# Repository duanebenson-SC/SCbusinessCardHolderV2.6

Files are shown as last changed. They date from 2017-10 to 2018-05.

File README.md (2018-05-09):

# SCbusinessCardHolderV2.6
Screaming Circuits business card holder, V2.6.

The second publicly released version of our electronic business card holder. V2.6 has most ports brought out to headers, and a different battery. Note that the silk screen calles out a CR2032 cell, but it actually takes a pair of CR1220 coin cells.

The Screaming Circuits business card holder is a multi-function device intended for your amusement and as a demonstration of our workmanship.

The current version of the card holder, V2.6, uses a PIC18F46K22 microcontroller. The design will work fine with other members of the PIC18F??K22 family. However, it you change the variant, you will need to uncomment the corresponding #define in globals.h, under the personality settings section.

The .brd and .sch are CAD files for Autodesk Eagle version 8.5 or newer.

Operation:
1. Turn on power and place cards between the header pins and user buttons. The dievice will sleep until a card is removed.

2. The bottom edge of the board has a small ruler, marked in inches and fractions of an inch.

3. With power on, hold the device so the ruler on on a flat surface. As you tilt it side to side, the LEDs will act as a bubble level

4. With power off, if you hold both buttons and then turn power on, all the LEDs will light up. Pressing User 2 will switch to normal mode.
4a. Press and hold User 1 and power on will light up all green LEDs.
4b. Press and hold User 2 and power on will light up all red LEDs.

5. With power on, pressing the User buttons will run a quick flashing patterm - unique for each button.

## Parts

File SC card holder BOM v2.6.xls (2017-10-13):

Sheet: BOM
Item # | Qty | Ref Des | Manufacturer | Manf part num | DigiKey Part number | Description | Package | Type | Side | Notes | Qty 1 | $ Ext | Qty 550 | Qty needed @550 | Ord Qty | $ Ext
1 | 1 | U1 | Microchip | PIC18F46K22-I/MV | PIC18F46K22-I/MV-ND | MCU | UQFN40 | BGA | Top |  | 2.29 | 2.29 | 1.9 | 550 | 600 | 1140.00
2 | 1 | U2 | Freescale | MMA8452QR1 | MMA8452QR1CT-ND | Accelerometer | QFN16 | BGA | Top |  | 1.43 | 1.43 | 1.02 | 550 | 600 | 612.00
3 | 10 | D1, D3, D5, D7, D9, D11, D13, D15, D17, D19 | Kingbright | APHHS1005SURCK | 754-1104-1-ND | LED red | 0402 | SMT | Top |  | 0.44 | 4.40 | 0.14928 | 5500 | 6000 | 895.68
4 | 9 | D2, D4, D6, D8, D10, D12, D14, D16, D18 | Kingbright | APG1005CGC-T | 754-1811-1-ND | LED green | 0402 | SMT | Top |  | 0.46 | 4.14 | 0.0936 | 4950 | 5500 | 514.80
5 | 5 | C1, C2, C3, C4, C5 | Taiyo | LMK105BJ104KV-F | 587-1227-1-ND | .1uf | 0402 | SMT | Top |  | 0.10 | 0.50 | 0.00325 | 2750 | 3000 | 9.75
6 | 1 | C6 | Samsung | CL05A475MQ5NRNC | 1276-1056-1-ND | 4.7uf | 0402 | SMT | Top |  | 0.21 | 0.21 | 0.0485 | 550 | 600 | 29.10
7 | 19 | R1-R19 | Stackpole | RMCF0402JT180R | RMCF0402JT180RCT-ND | 180 ohms | 0402 | SMT | Top |  | 0.10 | 1.90 | 0.00173 | 10450 | 12000 | 20.76
8 | 3 | R20, R21, R22 | Stackpole | RMCF0402JT10K0 | RMCF0402JT10K0CT-ND | 10K | 0402 | SMT | Top |  | 0.10 | 0.30 | 0.00328 | 1650 | 2000 | 6.56
9 | 1 | S1 | C&K Components | JS202011SCQN | 401-2002-1-ND | DPDT switch |  | SMT | Top |  | 0.46 | 0.46 | 0.3031 | 550 | 500 | 151.55
10 | 2 | S2, S3 | C&K Components | PTS645SK50SMTR92 LFS | CKN9087CT-ND | Momentary push |  | SMT | Top |  | 0.25 | 0.50 | 0.13125 | 1100 | 1200 | 157.50
11 | 2 | B1, B2 | MPD | BK-883 | BK-883-ND | 2032 holder |  | SMT | Bottom |  | 0.35 | 0.70 | 0.2448 | 1100 | 1200 | 293.76
12 | 2 | H1, H2 | Sullins | PREC006SFAN-RC | S1212EC-06-ND | 1x6 header ICSP |  | DNS | Top |  | 0.20 | 0.40 | 0.11586 | 1100 | 1200 | 139.03
13 | 4 | F1, F2, F3, F4 | 3M | SJ61A1 | SJ5746-0-ND | Rubber foot |  | DNS | Bottom |  | 0.10 | 0.39 | 0.0787 | 2200 | 2400 | 188.88
14 | 2 | Batt1, Batt2 | Energizer | CR2032VP | N189-ND | CR2032 battery |  | DNS | Bottom |  | 0.33 | 0.66 | 0.18411 | 1100 | 1200 | 220.93
 |  |  |  |  |  | PCB 3.5" x 1.65" |  |  |  |  |  | 0.00
 |  |  |  |  |  |  |  |  |  |  | Total parts, Qty 1 | 18.28 |  | Total parts, Qty 550 | 7.96 | 4380.30
 | Items 12, 13, and 14 need to be ordered and delivered to me, but not placed on the board |  |  |  |  |  |  | Assembly quote summary
 |  |  |  |  |  |  | BOM line items | 11
 | Note that item #13, the 3M feet only come in sheets of 144 |  |  |  |  |  | BGA | 2
 |  |  |  |  |  |  | SMT | 52
 |  |  |  |  |  |  | Thru-hole | 0
 |  |  |  |  |  |  | Total | 54

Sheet: LED
System V | 3
Diode drop | 0.385
 | 2.615
LED V | 1.95
C | 0.0036 | Max LED C | 0.0828
R V | 0.665
R Ohm | 184.7222222

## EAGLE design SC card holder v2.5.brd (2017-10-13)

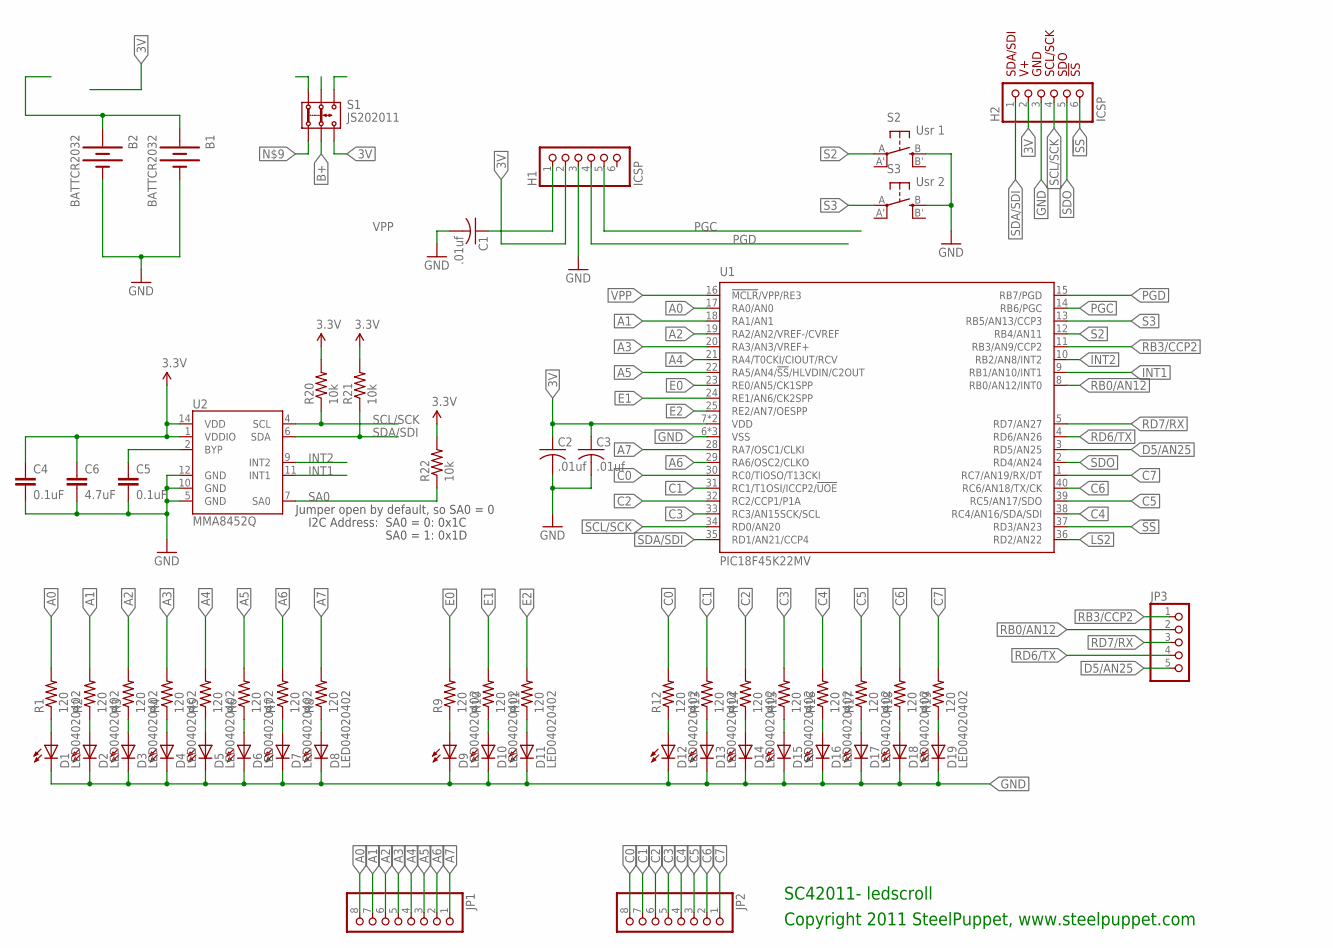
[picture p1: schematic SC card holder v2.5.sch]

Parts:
B1, B2: BATTCR2032; BATT_2032_SMT
C1, C2, C3: .01uf; C0402K
C4, C5: 0.1uF; 0402-CAP
C6: 4.7uF; 0402-CAP
D1, D2, D3, D4, D5, D6, D7, D8, D9, D10, D11, D12, D13, D14, D15, D16, D17, D18, D19: LED04020402; LED0402
H1, H2: ICSP; 1X06-S
JP1, JP2: PINHD-1X08_2.54-S; 1X08-S
JP3: PINHD-1X05_2.54-S; 1X05-S
R1, R2, R3, R4, R5, R6, R7, R8, R9, R10, R11, R12, R13, R14, R15, R16, R17, R18, R19: 120; R0402
R20, R21, R22: 10k; 0402-RES
S1: JS202011; JS202011SMT
S2: Usr 1; EVQ-Q2
S3: Usr 2; EVQ-Q2
U1: PIC18F45K22MV; QFN40-5X5
U2: MMA8452Q; QFN-16_0.5MM

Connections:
3V: C2.1, C3.1, C4.1, C6.1, H1.2, H2.2, R20.2, R21.2, R22.2, S1.3 (3.2), S1.4 (3.1), U1.7 (VDD), U1.26 (VDD), U2.1 (VDDIO), U2.14 (VDD)
!SS: H2.6, U1.37 (RD3/AN23)
A0: JP1.8, R1.2, U1.17 (RA0/AN0)
A1: JP1.7, R2.2, U1.18 (RA1/AN1)
A2: JP1.6, R3.2, U1.19 (RA2/AN2/VREF-/CVREF)
A3: JP1.5, R4.2, U1.20 (RA3/AN3/VREF+)
A4: JP1.4, R5.2, U1.21 (RA4/T0CKI/CIOUT/RCV)
A5: JP1.3, R6.2, U1.22 (RA5/AN4/!SS!/HLVDIN/C2OUT)
A6: JP1.2, R7.2, U1.29 (RA6/OSC2/CLKO)
A7: JP1.1, R8.2, U1.28 (RA7/OSC1/CLKI)
B+: B1.1 (+), B1.3 (+), B2.1 (+), B2.3 (+), S1.2 (2.2), S1.5 (2.1)
BYP: C5.1, U2.2 (BYP)
C0: JP2.8, R12.2, U1.30 (RC0/TIOSO/T13CKI)
C1: JP2.7, R13.2, U1.31 (RC1/T1OSI/ICCP2/!UOE)
C2: JP2.6, R14.2, U1.32 (RC2/CCP1/P1A)
C3: JP2.5, R15.2, U1.33 (RC3/AN15SCK/SCL)
C4: JP2.4, R16.2, U1.38 (RC4/AN16/SDA/SDI)
C5: JP2.3, R17.2, U1.39 (RC5/AN17/SDO)
C6: JP2.2, R18.2, U1.40 (RC6/AN18/TX/CK)
C7: JP2.1, R19.2, U1.1 (RC7/AN19/RX/DT)
D5/AN25: JP3.5, U1.3 (RD5/AN25)
E0: R9.2, U1.23 (RE0/AN5/CK1SPP)
E1: R10.2, U1.24 (RE1/AN6/CK2SPP)
E2: R11.2, U1.25 (RE2/AN7/OESPP)
GND: B1.2 (-), B2.2 (-), C1.2, C2.2, C3.2, C4.2, C5.2, C6.2, D1.C, D2.C, D3.C, D4.C, D5.C, D6.C, D7.C, D8.C, D9.C, D10.C, D11.C, D12.C, D13.C, D14.C, D15.C, D16.C, D17.C, D18.C, D19.C, H1.3, H2.3, S2.B (S), S3.B (S), U1.6 (VSS), U1.27 (VSS), U1.41 (VSS), U2.5 (GND), U2.10 (GND), U2.12 (GND)
INT1: U1.9 (RB1/AN10/INT1), U2.11 (INT1)
INT2: U1.10 (RB2/AN8/INT2), U2.9 (INT2)
LS2: U1.36 (RD2/AN22)
unnamed: D1.A, R1.1
unnamed: D2.A, R2.1
unnamed: D3.A, R3.1
unnamed: D4.A, R4.1
unnamed: D9.A, R9.1
unnamed: D10.A, R10.1
unnamed: D11.A, R11.1
unnamed: D13.A, R13.1
unnamed: D14.A, R14.1
unnamed: D15.A, R15.1
unnamed: D12.A, R12.1
unnamed: D6.A, R6.1
unnamed: D7.A, R7.1
unnamed: D16.A, R16.1
unnamed: D17.A, R17.1
unnamed: D8.A, R8.1
unnamed: D5.A, R5.1
unnamed: D18.A, R18.1
unnamed: D19.A, R19.1
PGC: H1.5, U1.14 (RB6/PGC)
PGD: H1.4, U1.15 (RB7/PGD)
RB0/AN12: JP3.2, U1.8 (RB0/AN12/INT0)
RB3/CCP2: JP3.1, U1.11 (RB3/AN9/CCP2)
RD6/TX: JP3.4, U1.4 (RD6/AN26)
RD7/RX: JP3.3, U1.5 (RD7/AN27)
S2: S2.A, U1.12 (RB4/AN11)
S3: S3.A, U1.13 (RB5/AN13/CCP3)
SA0: R22.1, U2.7 (SA0)
SCL/SCK: H2.4, R20.1, U1.34 (RD0/AN20), U2.4 (SCL)
SDA/SDI: H2.1, R21.1, U1.35 (RD1/AN21/CCP4), U2.6 (SDA)
SDO: H2.5, U1.2 (RD4/AN24)
VPP: C1.1, H1.1, U1.16 (!MCLR!/VPP/RE3)

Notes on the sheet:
SC42011- ledscroll
Copyright 2011 SteelPuppet, www.steelpuppet.com
SDA/SDI
GND
SCL/SCK
SDO
!SS
I2C Address:
SA0 = 0: 0x1C
SA0 = 1: 0x1D
Jumper open by default, so SA0 = 0

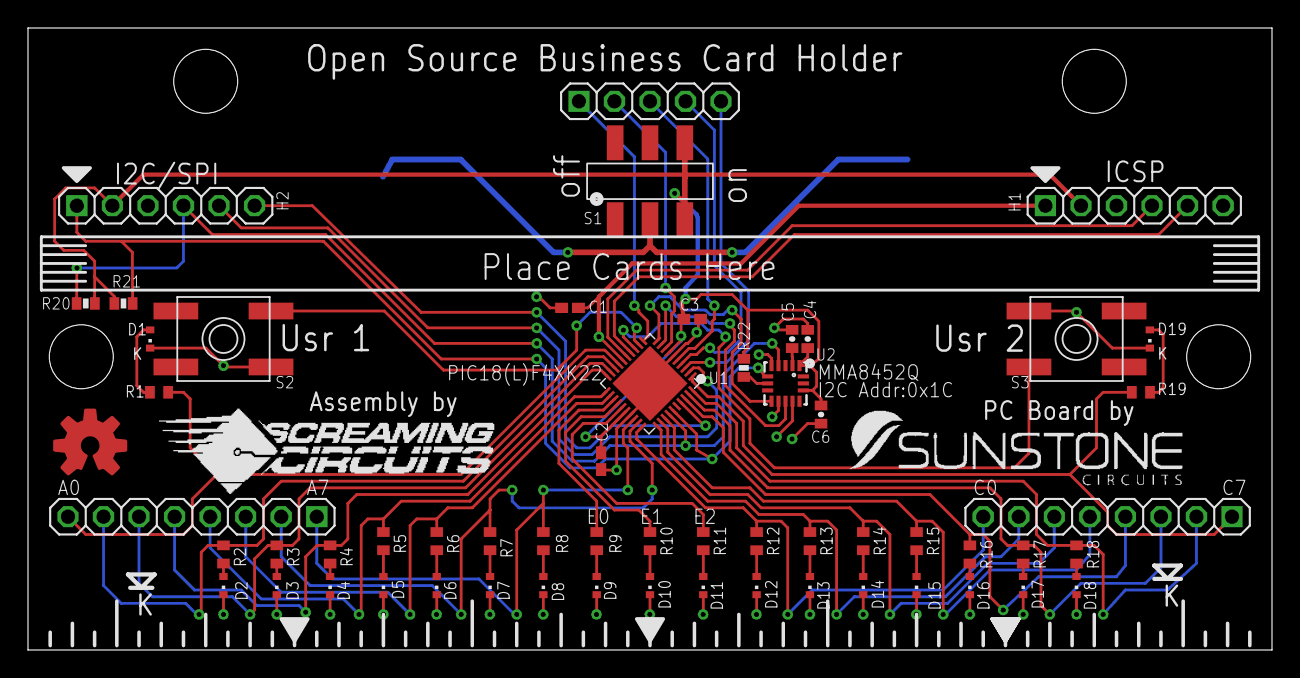
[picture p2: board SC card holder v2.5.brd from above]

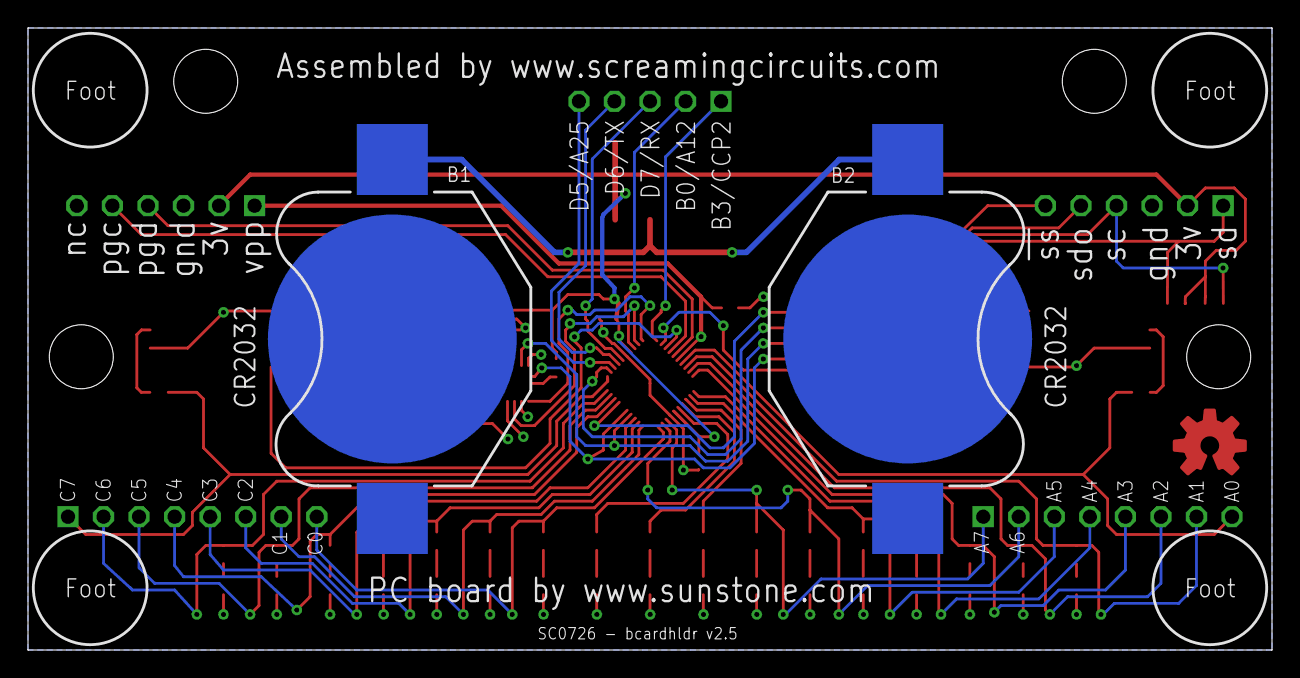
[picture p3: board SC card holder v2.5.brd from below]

Board: 2 copper layers, 88.9 x 44.5 mm, 62 parts (2 on the bottom side), 59 nets.

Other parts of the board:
U$1: SUNSTONE-LOGO
U$2: OSHWLOGO_TOP_0.2
U$3: SC-LOGO

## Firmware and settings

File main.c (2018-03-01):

// ##########################################################################
// ##########################################################################
// Screaming Circuits Business card holder
//
// Written by Duane Benson
// 9/01/16
//
// Open source business card holder and bubble level
//
// Communicates via by I2C
// For MCU: PIC18F46K22 / PIC18F45K22 / PIC18F44K22 / PIC18F43K22
// 
//
// Edit history:
//
// ********************************************

// ####
// #### Project specific notes
// ####

// ####
/*
 * File:   main.c
 * Author: Duane
 *
 * Created on February 21, 2013, 12:06 PM
 */
// #### #### #### #### #### #### #### #### #### #### #### #### #### ####
// #### Defines
// #### #### #### #### #### #### #### #### #### #### #### #### #### ####

/******************************************************************************/
/* Files to Include                                                           */
/******************************************************************************/

#include <xc.h>        /* XC8 General Include File */
#include "globals.h"
#include "system.h"        /* System funct/params, like osc/peripheral config */
#include "user.h"          /* User funct/params, such as InitApp */
#include "configuration_bits.c"

/******************************************************************************/
/* User Global Variable Declaration                                           */
/******************************************************************************/

// See globals.

/******************************************************************************/
/* Main Program                                                               */
/******************************************************************************/

void main(void)
{
    int x, i, y, z;
    char PULSEdata, TRANSdata;

    /* Configure the oscillator for the device */
    ConfigureOscillator();

    /* Initialize I/O and Peripherals for application */
    InitApp();

    // Test patterns
    if (!PORTBbits.RB4 && !PORTBbits.RB5) { // Bothe Usr1 and Usr2 held at start up: All LEDs on
        LED0 = 1;
        LED1 = 1;
        LED2 = 1;
        LATA = 0xff;
        LATC = 0xff;
        delayLong(10);
        while (PORTBbits.RB5);
    } else if (!PORTBbits.RB4) {    // Usr1 held at start: all green LEDs on
        LED1 = 1;
        LATA = 0xAA;
        LATC = 0x55;
        delayLong(10);
        while (PORTBbits.RB5);
    } else if (!PORTBbits.RB5) {    // Usr2 held at start: all red LEDs on
        LED0 = 1;
        LED2 = 1;
        LATA = 0x55;
        LATC = 0xAA;
        delayLong(10);
        while (PORTBbits.RB5);
    }

    LATA = 0x00;
    LATC = 0x00;

    LED1 = 1;
    for (x = 0; x < 10; x++){
        LED0 = !LED0;
        LED1 = !LED1;
        LED2 = !LED2;
        delayLong(1);
    }

    LED0 = 0;
    LED1 = 0;
    LED2 = 0;

    MMAdata = readRegister(0x0D);  // Read WHO_AM_I register
    if (MMAdata == 0x2A) { // WHO_AM_I should always be 0x2A
        initMMA8452(2, 0);  // init the accelerometer if communication is OK
    } else {
        LATA = MMAdata;
        while(1) ; // Loop forever if communication doesn't happen
    }
    
    RBIF = 0;           // Clear flags
    INT1IF = 0;
    INT2IF = 0;
    Usr1 = 0;
    Usr2 = 0;
    Int1 = 0;
    Int2 = 0;

    INTCONbits.GIE = 1;

 // Original while loop to go with the original ISR
    while (1) {
        //if (Usr1 || Xval > 0x90) {
        //    bubbleLevel();
        if (Xval > 0x90) {
            bubbleLevel();
        } else if (Usr1) {
            flashAllOutward(3);
            Usr1 = 0;
        } else if (Usr2) {
            bubbleGum(6);
            Usr2 = 0;
        } else if (Int1) {
            flashAllOutward(1);
            Int1 = 0;
        } else if (Int2) {
            respondToAccel();
            Int2 = 0;
        } else {
            Sleep();
        }
    }
}

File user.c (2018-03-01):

/******************************************************************************/
/* Files to Include                                                           */
/******************************************************************************/

#include <xc.h>        /* XC8 General Include File */
#include "globals.h"
#include "user.h"
#include "system.h"

/******************************************************************************/
/* User Functions                                                             */
/******************************************************************************/

/* <Initialize variables in user.h and insert code for user algorithms.> */

void InitApp(void)
{
    /* TODO Initialize User Ports/Peripherals/Project here */
    TRISA = 0x00;
    TRISB = 0x00;
    TRISC = 0x00;
    TRISD = 0x00;
    TRISE = 0x00;

    LATA  = 0x00;
    LATB  = 0x00;
    LATC  = 0x00;
    LATD  = 0x00;
    LATE  = 0x00;

    ANSELA = 0x00;
    ANSELB = 0x00;
    ANSELC = 0x00;
    ANSELD = 0x00;
    ANSELE = 0x00;

    // Ports set to input for input switches and interrupts
    TRISB   |= 1 << 5;      // RB5 is input: Usr 2
    TRISB   |= 1 << 4;      // RB4 is input: Usr 1
    TRISB   |= 1 << 1;      // RB1 is input: Int 1 from accelerometer
    TRISB   |= 1 << 2;      // RB2 is input: Int 2 from accelerometer

    // Usr1 and Usr2 are normally-open active low. They need to pull-up
    WPUB4 = 1;              // Weak pull-up for RB4 / S2 / Usr 1
    WPUB5 = 1;              // Weak pull-up for RB5 / S3 / Usr 2

    // MMA8452 is set up with open drain, active-low interrupt lines
    //WPUB0 = 0;              // Weak pull-up for Int1
    WPUB1 = 0;              // Weak pull-up for Int1
    WPUB2 = 0;              // Weak pull-up for Int2
    RBPU = 0;               // 0 = enable pull-ups on PORTB, provided individual WPUB bits are set

    // Interrupts
    IPEN  = 0;              // Disable Interrupt prioritoes, as they are not needed
    INTCON = 0b00000000;    // Start with everything cleared

    // MMA8452 is set up with push-pull, active-high interrupt lines
    INTEDG1 = 1;            // Int1 pin interrupt on: 1 = rising edge, 0 = falling edge
    INTEDG2 = 1;            // Int2 pin interrupt on: 1 = rising edge, 0 = falling edge

    IOCBbits.IOCB4 = 1;     // Enable IOC (Interrrupt on change) on pin RB4
    IOCBbits.IOCB5 = 1;     // Enable IOC on pin RB5

    RBIF = 0;               // Clear interrupt flags
    INT1IF = 0;
    INT2IF = 0;

    INT1IE = 1;             // Enable interrupt pin 1: Accelerometer interrupt
    INT2IE = 1;             // Enable interrupt pin 2: Accelerometer interrupt

    RBIE = 1;               // Enable Port B int on change: RB4 and RB5 are Usr 1 and Usr 2

    // Set I2C pins as inputs
    TRISD |= 1 << 0;        // RD0 = SCL2/SCK2
    TRISD |= 1 << 1;        // RD1 = SDA2/SDI2

    SSP2ADD = 0x9F;         // 100 KHz I2C clock with 64 MHz system clock
    SSP2STATbits.SMP = 1;   // Slew off
    SSP2CON1bits.SSPEN = 1; // Enable I2C
    SSP2CON1 = 0b00101000;

// setting and clearing the appropriate SSPxM bits in the SSPxCON1 register and by setting the SSPxEN bit.
}


// Delay time in multiples of 10 ms
void delayLong(unsigned long x) {
    unsigned long i;
    for (i = 0; i < x; i++) {
        __delay_ms(10);
    }
}


void bubbleLevel() {
        GIE = 0;        // Turn off all interrupts
        while(!PORTBbits.RB4 || Xval > 0x90) {
            getAccel();
            LED1 = 1;
            if (Ysign) {
                //Yval = Yval - 0xf0;
                LED2 = 0;
                LED0 = 0;
                LATC = 0x00;
                LATA = 0x00;
                if (Yval > 0x10) LED0 = 1;
                if (Yval > 0x30) LATA = 0b10000000;
                if (Yval > 0x50) LATA = 0b11000000;
                if (Yval > 0x70) LATA = 0b11100000;
                if (Yval > 0x90) LATA = 0b11110000;
                if (Yval > 0xB0) LATA = 0b11111000;
                if (Yval > 0x100) LATA = 0b11111100;
                if (Yval > 0x180) LATA = 0b11111110;
                if (Yval > 0x200) LATA = 0b11111111;
            } else {
                Yval = (Yval - 0x10) * 0.9;
                LED0 = 0;
                LED2 = 0;
                LATA = 0x00;
                LATC = 0x00;
                if (Yval > 0x10) LED2 = 1;
                if (Yval > 0x30) LATC = 0b00000001;
                if (Yval > 0x50) LATC = 0b00000011;
                if (Yval > 0x70) LATC = 0b00000111;
                if (Yval > 0x90) LATC = 0b00001111;
                if (Yval > 0xB0) LATC = 0b00011111;
                if (Yval > 0x100) LATC = 0b00111111;
                if (Yval > 0x180) LATC = 0b01111111;
                if (Yval > 0x200) LATC = 0b11111111;
            }
        }
            
        if (PORTBbits.RB4) {
            allOff();
            RBIF = 0;
            Usr1 = 0;
            GIE = 1;
            delayLong(1);
        }

}


void respondToAccel() {
    getAccel();
            if ((ACTdataP & 0b01000000) == 0b01000000) {    // Z axis
                allOn(5);
                if ((ACTdataP & 0b00000100) == 0b00000100) {
                    flashLeft(2);
                } else {
                    flashRight(2);
                }
            } else if ((ACTdataP & 0b00100000) == 0b00100000) {  // Y axis
                allRed(5);
                if ((ACTdataP & 0b00000010) == 0b00000010) {
                    flashLeft(2);
                } else {
                    flashRight(2);
                }
            } else if ((ACTdataP & 0b00010000) == 0b00010000) { // X axis
                allBlue(5);
                if ((ACTdataP & 0b00000001) == 0b00000001 ) {
                    flashLeft(2);
                } else {
                    flashRight(2);
                }
            } else {
                flashAllInward(1);
            }
}


void flashAllInward(int x) {

    for (int i = 0; i < x; i++) {
        LED0 = 0;
        LED1 = 1;
        LED2 = 0;
        LATA = 0b00000001;
        LATC = 0b10000000;
        delayLong(1);
        for (int k = 0; k < 8; k++) {
            LATA = LATA << 1;
            LATC = LATC >> 1;
            LED0 = !LED0;
            LED1 = !LED1;
            LED2 = !LED2;
            delayLong(1);
        }
    }
    LED0 = 0;
    LED1 = 0;
    LED2 = 0;
}

void flashAllOutward(int x) {

    for (int i = 0; i < x; i++) {
        LED0 = 1;
        LED1 = 0;
        LED2 = 1;
        LATA = 0b10000000;
        LATC = 0b00000001;
        delayLong(1);
        for (int k = 0; k < 8; k++) {
            LATA = LATA >> 1;
            LATC = LATC << 1;
            LED0 = !LED0;
            LED1 = !LED1;
            LED2 = !LED2;
            delayLong(1);
        }
    }
    LED0 = 0;
    LED1 = 0;
    LED2 = 0;
}
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
